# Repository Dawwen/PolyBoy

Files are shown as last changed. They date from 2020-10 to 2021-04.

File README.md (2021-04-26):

<p align="center">
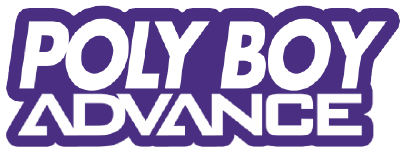
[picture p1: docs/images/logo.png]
PolyBoy Advance
  
</p>

# PolyBoy Advance

**Course :** Arduino

**Supervisors :** P. Masson, N. Abderrahmane

**Date :** December 2018 - March 2019

## Description

The goal of this project is to create a portable console based on Arduino Due. For this purpose, our portable console is equipped with a `TFT` screen, a `SD` card reader, a speaker, a gyroscope, a bluetooth module and other sensors and actuators. In the future, we think of developing an interface allowing to launch several games and applications.

## Authors

- [João Brilhante](https://github.com/JoaoBrlt)
- [Olivier Doussaud](https://github.com/Dawwen)

## License

This project is licensed under the GPLv3 License - see the [LICENSE](LICENSE) file for details.

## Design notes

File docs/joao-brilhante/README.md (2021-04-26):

<p align="center">
  Poly Boy Advance
</p>

## Une console portable basée sur Arduino Due
Notre projet est de créer une console portable basée sur Arduino Due. Elle sera notamment équipée d’un écran `LCD TFT`, d’un lecteur de carte micro `SD`, d’un haut-parleur, d’un gyroscope, d’un module bluetooth… De plus, elle devrait posséder une interface permettant de lancer plusieurs jeux et applications.

## Séance 1 : 14/12/18
Notre premier soucis a été de trouver un écran ayant une fréquence de rafraîchissement assez grande. En effet, dans le cadre des jeux vidéo, la fréquence de rafraîchissement est primordiale pour un affichage correct et des transitions fluides.

### Écran TFT à 8 bits en parallèle
<p align="center">
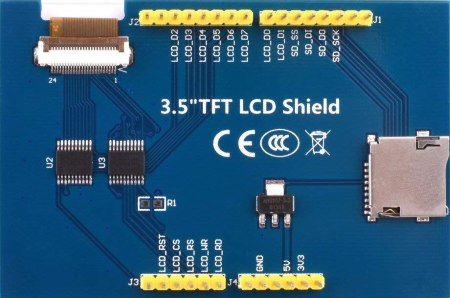
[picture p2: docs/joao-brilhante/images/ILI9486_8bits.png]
Écran TFT 8 bits de 3.5 pouces
  
</p>

Nous avons tout d’abord opté pour un écran `LCD TFT` (*Thin-Film Transistor*) ayant 5 pins de contrôle, 8 pins de communication et un contrôleur `ILI9486`.

En effet, nous pensions, à prime abord, que le nombre de pins de communication impacterait grandement la fréquence de rafraîchissement de l’écran.

Cependant, après quelques tests, nous avons constaté que l’écran pouvait prendre jusqu’à deux minutes pour rafraîchir individuellement chaque pixel avec une couleur aléatoire.

### Écran TFT à liaison SPI
<p align="center">
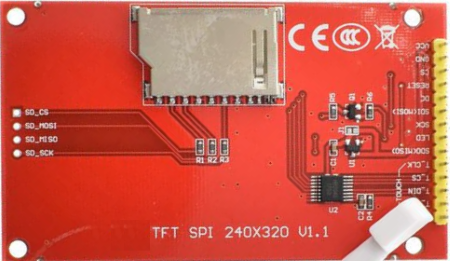
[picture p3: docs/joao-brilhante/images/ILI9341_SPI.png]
Écran TFT SPI de 3.2 pouces
  
</p>

Nous avons alors opté pour un écran `LCD TFT` à liaison `SPI` (*Serial Peripheral Interface*) qui n’utilise que 3 pins de contrôle, 4 pins de communication et un contrôleur `ILI9341`. L’avantage de la liaison `SPI` est son débit de données bien plus important notamment en mode `DMA` (*Direct Memory Access*).

De plus, après quelques recherches, nous avons trouvé une bibliothèque [ILI9341_due](https://github.com/marekburiak/ILI9341_due) très complète conçue pour notre contrôleur d'écran et pour Arduino Due. Cette bibliothèque correspond parfaitement à notre projet et implémente d'ores et déjà des fonctions d'affichage indispensables.

Après quelques tests, nous parvenons à afficher des textes, des formes et des images et à les animer. Cependant, nous avons toujours affaire à quelques artéfacts d'affichage qui sont dû à la fréquence de rafraîchissement de l’écran que nous devons prendre en compte.

## Séance 2 : 18/12/18
Nous nous répartissons les tâches et je décide d'attaquer la gestion de la mémoire. En effet, toujours dans le cadre des jeux vidéo, un de nos plus gros soucis sera le stockage et l'accès aux ressources telles que les images et les sons.

Nous décidons d'utiliser pour cela un module de carte micro `SD` à liaison `SPI`. En effet, la mémoire `SRAM` et `FLASH` offerte par l'Arduino Due n'est pas suffisante pour stocker toutes les ressources. De plus, cela nous permettra de stocker les ressources de tous les jeux sans avoir à reflasher l'Arduino Due.

### Module carte micro SD
<p align="center">
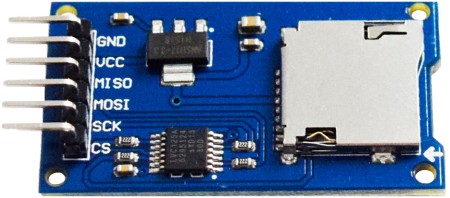
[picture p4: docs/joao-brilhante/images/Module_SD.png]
Module de carte SD
  
</p>

Après quelques recherches, je dois choisir entre deux bibliothèques de gestion de carte `SD` pour Arduino. La première bibliothèque [SD](https://www.arduino.cc/en/Reference/SD) est celle fournie par l'Arduino IDE. La deuxième bibliothèque [SdFat](https://github.com/greiman/SdFat) est celle que je choisis puisqu'il s'agit de la plus maintenue à jour par une communauté active. De plus, cette-denière permettrait un accès aux ressources bien plus rapide.

### Cartes micro SD
<p align="center">
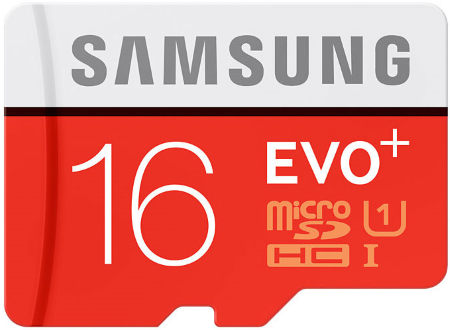
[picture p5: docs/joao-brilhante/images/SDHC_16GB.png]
Carte SDHC de 16 Go
  &nbsp;
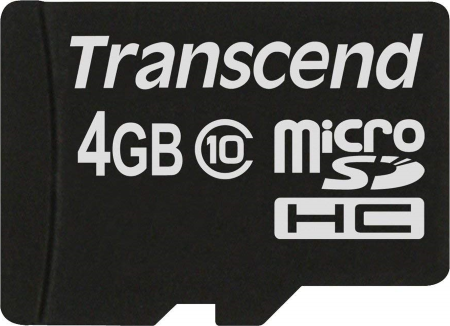
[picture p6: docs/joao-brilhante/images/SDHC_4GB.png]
Carte SDHC de 4 Go
  
</p>

Lors des premiers tests, il est nécessaire de trouver la plus grande fréquence de fonctionnement de notre carte micro `SD`. Dans un premier temps, j'essaie une carte micro `SDHC` de 16 Go et je constate que sa fréquence de fonctionnement est très basse. En effet, il semblerait que la fréquence de fonctionnement d'une carte `SD` soit d'autant plus grande que sa capacité est faible. Je décide alors d'utiliser une carte micro `SDHC` de 4 Go pour laquelle je trouve une fréquence de fonctionnement bien plus grande.

Il est ensuite très simple d'accéder à la mémoire et de manipuler les fichiers en lecture et en écriture. J'ajoute dès à présent une fonctionnalité permettant de désactiver la communication avec l'écran `TFT`, également en liaison `SPI`, lors de l'accès à la carte `SD` afin d'éviter les conflits.

## Séance 3 : 11/01/19
Dans l'optique d'un meilleur confort de jeu, nous décidons d'utiliser des boutons à membrane au lieu de boutons poussoirs. Je dois alors chercher les boutons, les membranes en caoutchouc et le circuit imprimé permettant leur fonctionnement. Malheureusement, les boutons à membrane sont souvent vendus sans le circuit imprimé, pour permettre la réparation de vieilles manettes.

### Manette de SNES
<p align="center">
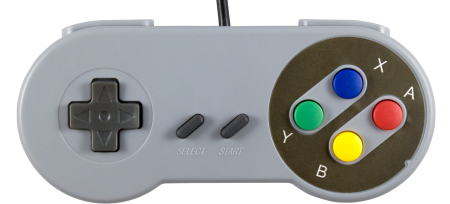
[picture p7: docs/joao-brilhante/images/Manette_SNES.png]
Manette de SNES
  
</p>

Je choisis une option assez simple qui consiste à réutiliser les composants d'une manette filaire de `SNES`.

### Composants de la manette
<p align="center">
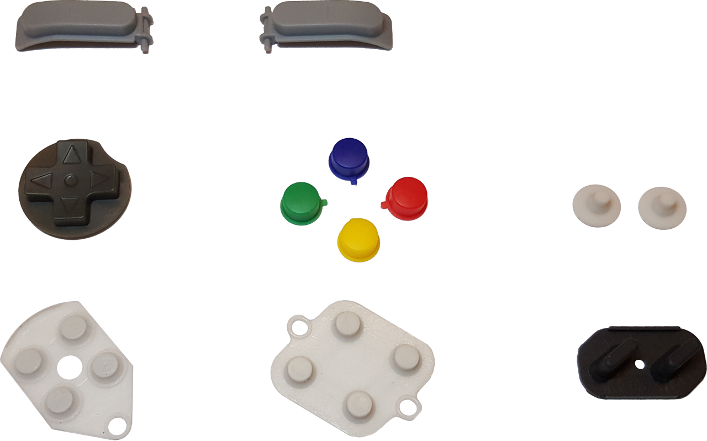
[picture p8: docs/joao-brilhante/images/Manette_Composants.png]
Composants de la manette
  
</p>

Il me suffit de démonter la manette puis de récupérer les boutons, les membranes et le circuit imprimé.

### Circuit imprimé de la manette
<p align="center">
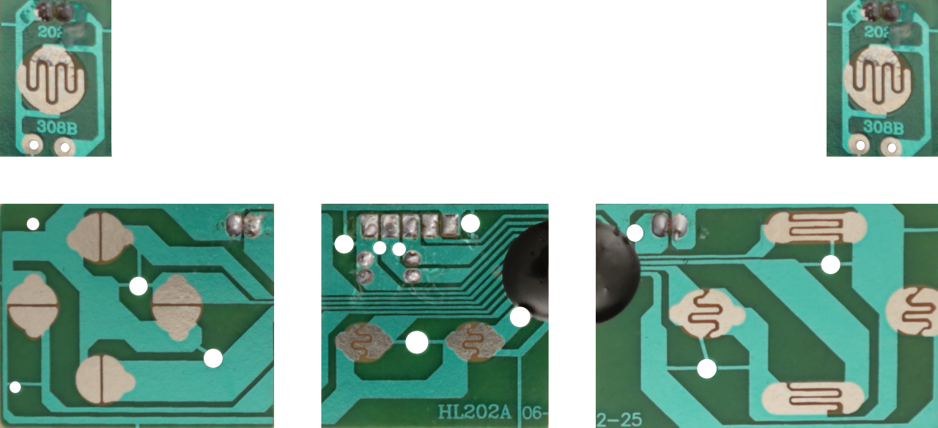
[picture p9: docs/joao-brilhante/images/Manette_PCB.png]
Circuit imprimé de la manette
  
</p>

Je découpe ensuite le circuit imprimé en cinq morceaux afin de pouvoir disposer les boutons plus aisément ultérieurement.
- Un morceau pour la croix directionnelle.
- Un morceau pour les boutons `Start` et `Select`.
- Un morceau pour les boutons `A`, `B`, `X` et `Y`.
- Deux morceaux pour les gachettes gauche et droite.

### Schéma du circuit imprimé
<p align="center">
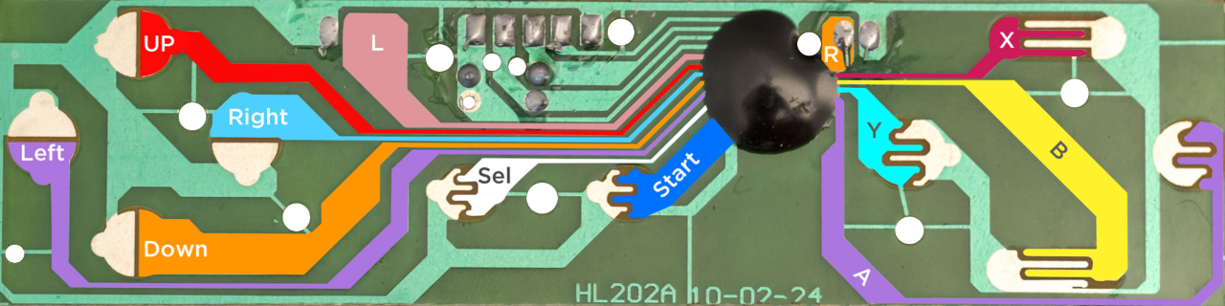
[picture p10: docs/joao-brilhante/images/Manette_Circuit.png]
Schéma du circuit imprimé
  
</p>

Enfin, je soude des fils sur les contacts des circuits imprimés afin de détecter la pression de chaque bouton. Pour l'instant, les fils sont suffisamment longs pour pouvoir disposer les boutons plus facilement lors du montage.

### Gestionnaire des boutons
Finalement, il ne me reste plus que le développement d'une bibliothèque permettant la gestion des boutons. Pour cela, je crée une structure de données pour pouvoir stocker toutes les informations des boutons telles que le nom, le pin, l'état, l'état précédent... etc.

Je développe ensuite une classe qui stocke tous les boutons et qui admet un certain nombre de fonctions. Ces fonctions permettent de récupérer facilement des informations utiles sur les boutons à partir de leur nom : le bouton est-il pressé ? le bouton a-t-il été relâché ? le bouton est-il pressé depuis un certain temps ? ... etc.

## Séance 4 : 18/01/19
Après ces quelques séances, nous avons déjà réussi à mettre en place la gestion de l'écran, des boutons et de la mémoire sur une carte micro `SD`. De ce fait, il nous semble important de réunir notre travail au plus vite pour valider ces fonctionnalités et aller plus loin dans le projet.

### Morpion
<p align="center">
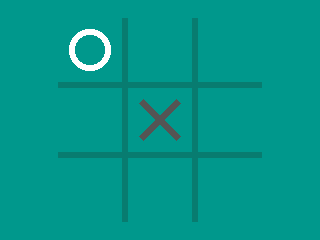
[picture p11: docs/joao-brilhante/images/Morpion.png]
Morpion
  
</p>

Je décide alors de coder le premier jeu simpliste de la console : un morpion ! Je commence par gérer l'affichage du jeu en utilisant les fonctions de la bibliothèque de l'écran. J'ajoute un sélecteur permettant de se déplacer et de valider son choix à l'aide des boutons à l'aide de la bibliothèque des boutons. J'implémente ensuite une vérification de victoire ou d'égalité des joueurs. Enfin, je crée un menu permettant au joueur de choisir son mode de jeu. En effet, le joueur peut choisir de jouer contre un autre joueur ou contre une intelligence artificielle simple.

### Modélisation 3D
<p align="center">
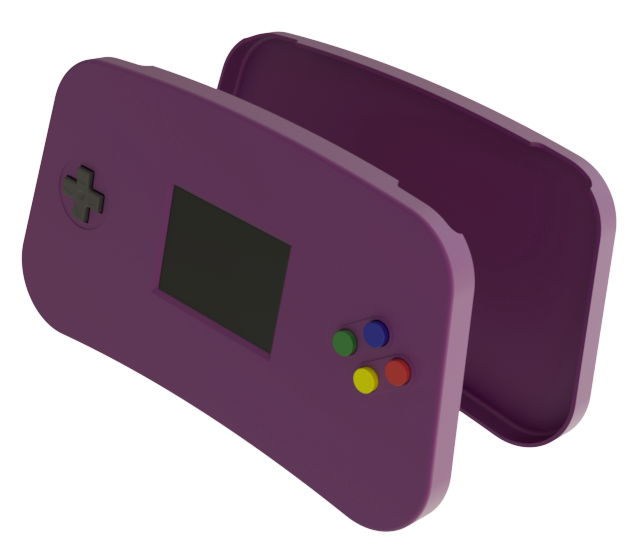
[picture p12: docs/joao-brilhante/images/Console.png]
Rendu 3D de la console
  
</p>

Afin d'obtenir le meilleur résultat possible, nous choisissons de faire imprimer en 3D le boitier de notre console. Pour cela, il est nécessaire de s'occuper d'ores et déjà de la modélisation 3D du boitier. J'utilise alors le logiciel <a href="https://www.autodesk.fr/products/inventor/overview">Inventor</a> pour modéliser l'intégralité des composants avec une grande précision pour un résultat au plus proche de la réalité. De plus, il est nécessaire de réfléchir à la meilleure disposition des composants pour la miniaturisation et l'ergonomie de la console.

### Quelques rendus
<p align="center">
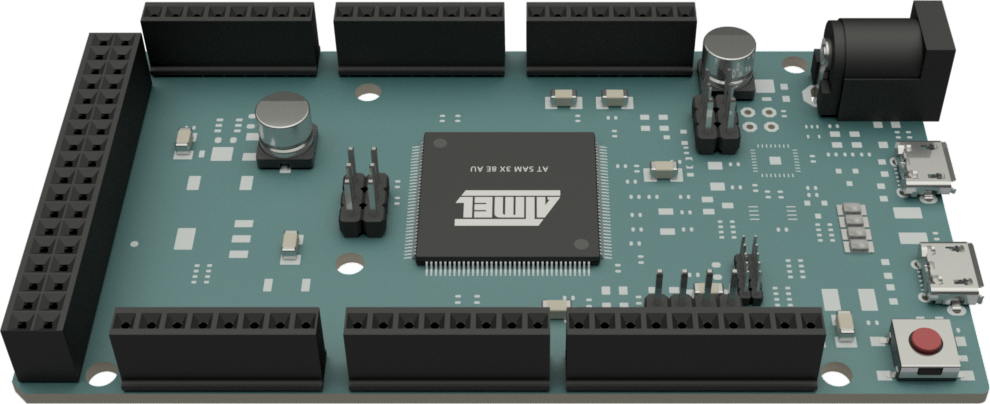
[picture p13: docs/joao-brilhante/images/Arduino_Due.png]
Arduino Due
  &nbsp;&nbsp;
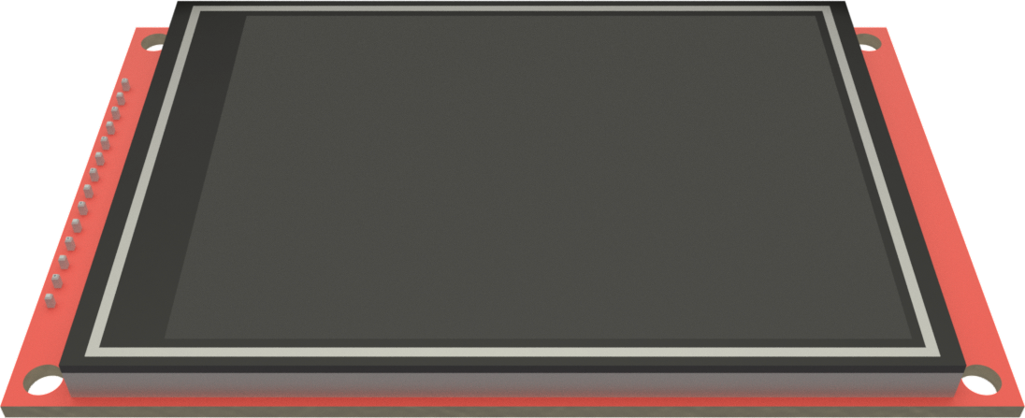
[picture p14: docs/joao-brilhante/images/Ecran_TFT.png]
Ecran TFT
  &nbsp;&nbsp;
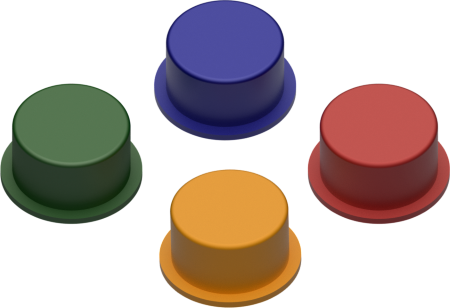
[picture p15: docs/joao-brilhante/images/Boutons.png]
Boutons ABXY
  &nbsp;&nbsp;
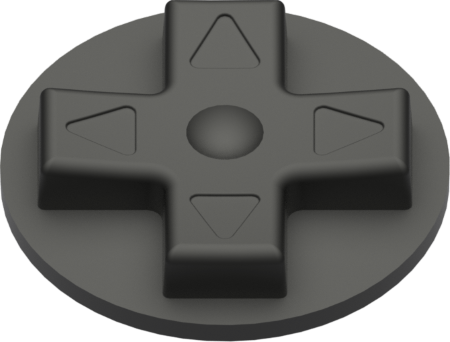
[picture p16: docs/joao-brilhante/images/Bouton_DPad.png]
Bouton des flèches directionnelles
  &nbsp;&nbsp;
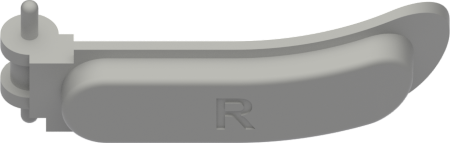
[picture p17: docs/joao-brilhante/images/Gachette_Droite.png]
Gachette droite
  &nbsp;&nbsp;
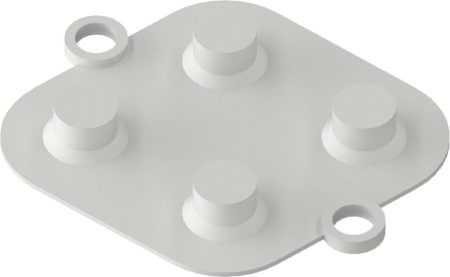
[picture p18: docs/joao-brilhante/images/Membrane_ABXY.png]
Membrane des boutons ABXY
  &nbsp;&nbsp;
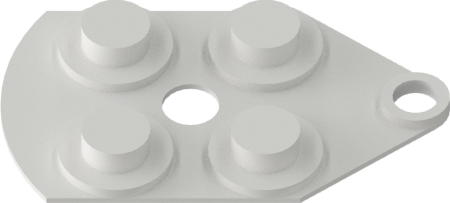
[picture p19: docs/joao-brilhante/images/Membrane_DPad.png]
Membrane du bouton des flèches directionnelles
  &nbsp;&nbsp;
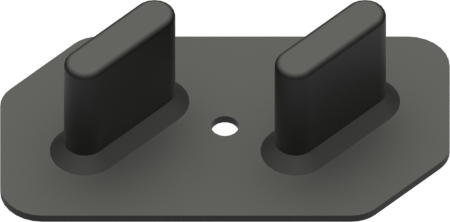
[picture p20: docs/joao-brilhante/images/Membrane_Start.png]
Membrane des boutons Start et Select
  
</p>

## Séance 5 : 05/02/19
Durant cette séance, je poursuis la modélisation 3D du boitier de la console. Le but est de penser au mieux la structure du boitier autant du point de vue extérieur, pour une bonne ergonomie et une certaine rigidité, que du point de vue intérieur, pour une bonne fixation des composants. De plus, je souhaite miniaturiser au maximum la console. L'enjeu est donc de taille puisque nous n'avons pas beaucoup d'espace pour les composants et plus beaucoup de temps pour réaliser des prototypes. Il s'agit alors de laisser une certaine marge à l'impression 3D pour mieux corriger et emboîter les deux parties du boitier a posteriori.

### Impression 3D
<p align="center">
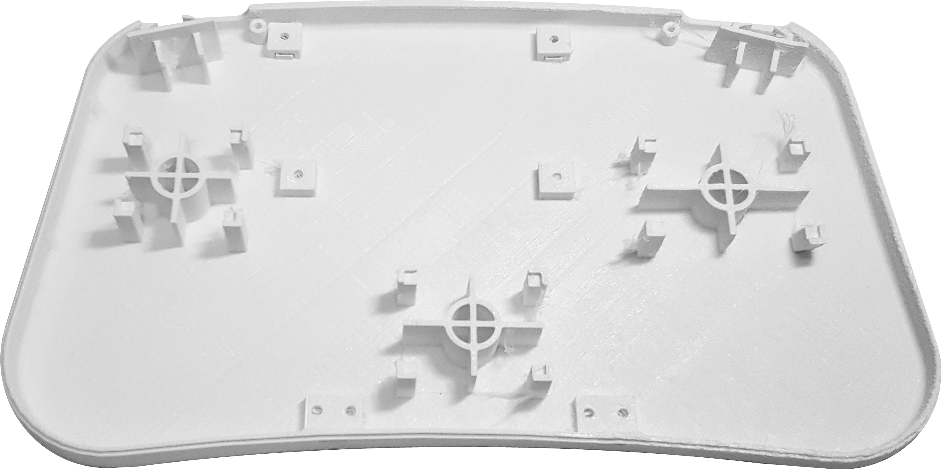
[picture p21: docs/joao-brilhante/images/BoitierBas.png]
Boitier bas
  
</p>

Une fois ce long processus terminé, je contacte le [SoFab](http://www.sofab.tv/), un atelier partagé de fabrication situé sur le campus Sophiatech, qui accepte notre projet d'impression 3D. Je parviens assez facilement à imprimer le bas du boitier. Cependant, pour l'impression 3D du haut du boitier, je suis confronté à un certain nombre de problèmes à cause de certaines extrusions. Après quelques aller-retour entre la modélisation et l'impression 3D, je parviens tout de même à imprimer le haut du boitier.

## Séance 6 : 13/02/19
L'impression 3D du boitier reste plutôt correcte cependant elle manque cruellement de précision.

### Corrections
<p align="center">
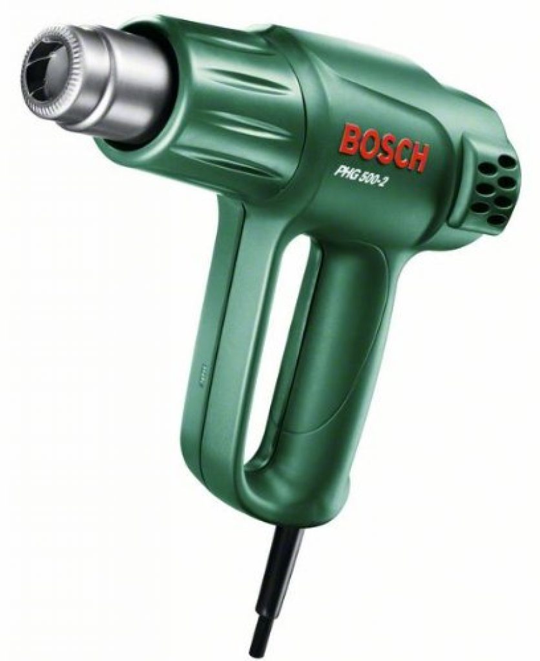
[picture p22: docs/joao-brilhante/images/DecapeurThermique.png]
Décapeur thermique
  &nbsp;&nbsp;
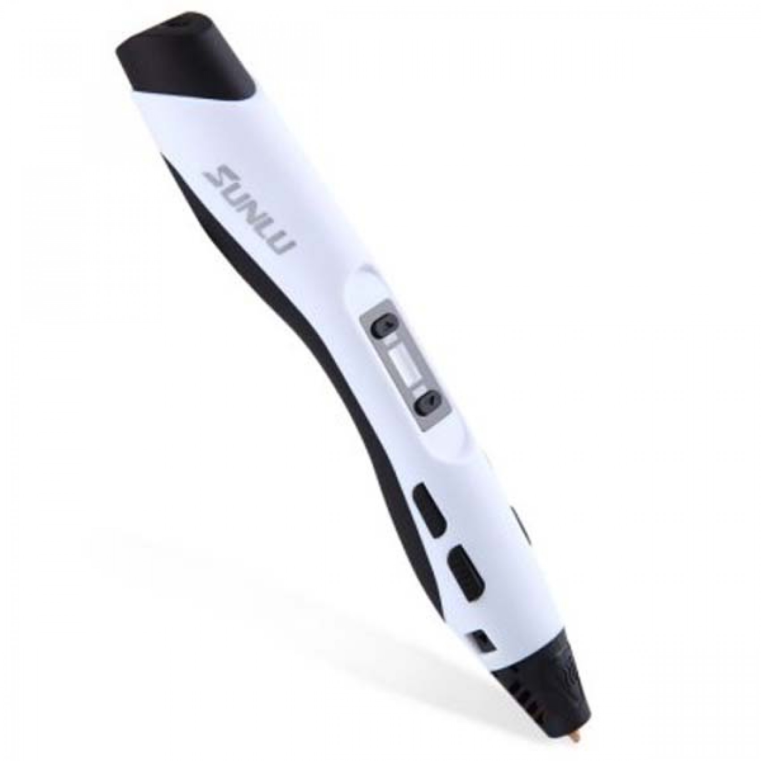
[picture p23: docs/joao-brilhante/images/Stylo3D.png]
Stylo 3D
  &nbsp;&nbsp;
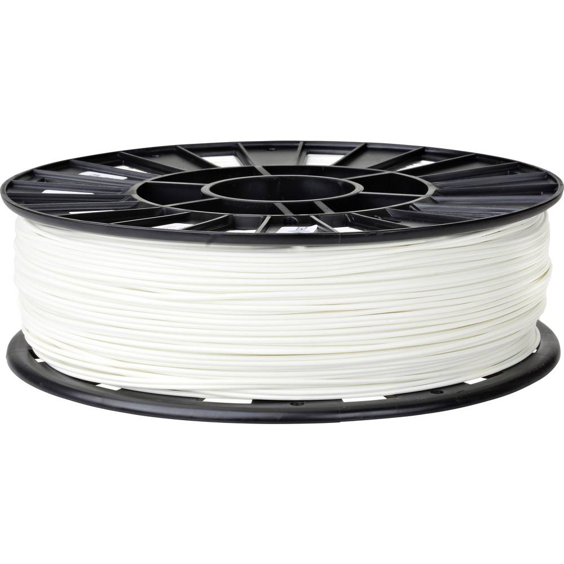
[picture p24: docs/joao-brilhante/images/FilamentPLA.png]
Filament PLA
  &nbsp;&nbsp;&nbsp;&nbsp;
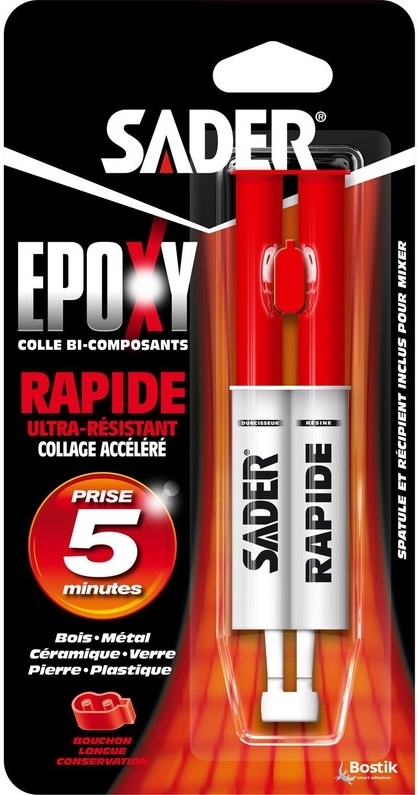
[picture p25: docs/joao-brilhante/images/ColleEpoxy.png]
Tubes de colle Epoxy
  
</p>

La prochaine étape est donc de corriger les erreurs d'impression en utilisant les mesures correctes du modèle 3D. Pour cela, j'utilise un décapeur thermique pour chauffer et redresser certaines parties du boitier. J'utile également un tube de colle Epoxy pour coller solidement certaines parties mal placées du boitier. J'utilise ensuite un stylo 3D accompagné d'un filament de PLA 1.75mm pour ajouter de la matière à certains endroits du boitier. Il ne me reste plus qu'à vérifier le bon emboitement et la fixation des composants à l'intérieur du boitier pour valider les corrections.

### Finitions
<p align="center">
  Mastic pour remplissage et finitions&nbsp;&nbsp;
  Peinture acrylique en spray&nbsp;&nbsp;
  Vernis mat en spray
</p>

Les deux parties du boitier s'emboitent désormais parfaitement. Je m'attaque donc au plus vite aux finitions. Pour cela, j'utilise un Mastic de remplissage et de finitions automobiles pour combler les creux des surfaces. Il me suffit d'appliquer la pâte sur les surfaces, d'attendre le séchage complet puis de poncer à l'aide de papiers abrasifs de différents grains et de manière progressive. J'applique ensuite trois couches de peinture violette acrylique en spray avant d'appliquer deux couches de vernis mat en spray.

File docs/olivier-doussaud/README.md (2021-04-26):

# PolyBoy Advance
## An Arduino Project
Notre projet est de créer une console portable basée sur Arduino Due. Elle sera notamment équipée d’un écran TFT, d’un lecteur de carte SD, d’un haut-parleur, d’un gyroscope, d’un module bluetooth… De plus, elle devrait posséder une interface permettant de lancer plusieurs jeux et applications.

### 14/12 : Séance 1
Après plusieurs recherches d'écrans :

1. **Un ili9486 3.5 inch** (8 pins de communications en parallèles)
2. **Un ili9341 3.2 inch** (16 pins de communications en parallèles)
3. **Un ili9341 3.2 inch** (communication en **SPI**)

On a décidé d'utiliser le **ili9341** en **SPI** qui était l'écran avec un rafraîchissement le plus rapide mais pas non plus suffisant. En cherchant plusieurs librairies qui n'accélérait pas le processus. On a trouve cette [librairie](https://github.com/marekburiak/ILI9341_due) avec une [video](https://www.youtube.com/watch?v=vnEwzN14BsU) montrant un mode du **SPI** plus rapide faite pour notre carte l'**Arduino Due**. Cette librairie accélère beaucoup le processus d'affichage et le met a un niveau suffisant pour faire des jeux. Cette librairie utilise le mode **DMA** ou Direct Memory Acess du **SPI** qui ne demande moins de ressource au micro-controller et permet l'exécution de code en parallele.

On arrive à afficher sur l'écran des formes géometriques et des images de toutes tailles. Le problème est d'afficher une image sur un **background**. On a reussi à afficher au maximum un **background** et un **sprite** dessus ([link](https://www.youtube.com/watch?v=tJE1cOGFOp4&feature=youtu.be)).
On a quand même un problème d'affichage liée au rafraichîssement de l'écran qui a pu être en partie reparé avec l'ajout d'un cap au **framerate** (nombre de fois que l'on finis un nouvelle frame en 1 seconde). On a donc bloqué le **framerate** à 60 **frame** par seconde. Le but maintenant est de faire que l'on ne rafraîchisse que la partie nécessaire de l'écran pour encore augmenter la vitesse et encore réduire les problèmes d'affichages.

### 18/12 : Séance 2

On a ajouté un **script** python pour convertir les images **bmp** en un **tableau** lisible par l'arduino. Ce **tableau** est à 1 dimension et contient les couleurs en valeur numérique codées en **RGB 565** (5 bits pour le rouge, 6 bits pour le vert et 5 bits pour le rouge). Cela nous permettra de facilement copier des images sur l'arduino et de les afficher. On a aussi travaillé sur la **gestion de l'affichage** de l'écran. Avant on redessiner complètement le **background** pour chaque nouvelle **frame** puis les **sprites** qui étaient au 1er plan. Cette méthode n'étant pas des plus rapide et ajoutant au problèmes que l'on puisse dessiner pendant que l'écran se rafraîchisse.  On a créé une **classe** sprite qui redessinera que les zones modifiées de l'écran, diminuant les données à envoyer entre l' **écran** et l'**arduino due**. On a cependant eu un problème avec notre **librairie**, la modification du bas de l'ecran, ne redessinait pas la bonne partie du **background** (elle dessinait le partie haute du background avec un decalage).  Le problème venant que la librairie codait l'**offset** sur **16bits** au lieu de **32bits** ce qui faisait que l'offset ne pouvait  pas atteindre les dernieres valeurs du background. On a ajouter des méthodes a la **librairie** pour résoudre ce problème en codant l'**offset** sur **32bits**.

Les problèmes persistant sont :

1. Le fait que l'on puisse dessiner pendant que l'écran se rafraîchisse (fait que le sprite se mélange au background)
2. On ne dispose pas de transparence sur l'ecran pour le moment

### 11/01 : Séance 3

Je me suis occupé du problème de transparence que l'on avait. Pour gerer la transparence je dois choisir une couleur qui sera consideré comme transparent la couleur utilisé communement est le **magenta** . Pour résoudre ce problème j'ai modifié notre **script** qui transfornait les images **bmp** en fichier pour l'arduino.A la place de copier tout l'image je regarde le contour du contenu de l'image et je prend que ce qu'il y a à l'interieur. Ce qui fait que les sprites n'auront pas forcément de forme carré. Cela ne gére que une partie de la transparence, cela permet d'enlever les fond noir de l'image mais laisse les pixel magenta à l'interieur du contour visible.

<p align="center">
  1ere essai de transparence
</p>

Pour résoudre ce problème on doit s'occuper du coté de l'arduino et plus spécifiquement du coté de la librairie. J'ai modifié la librairie en faisant que quand il affiche un **sprite** si la couleur est **magenta** il n'affiche pas **magenta** mais la couleur du **background** ce qui corrige le problème restant.

<p align="center">
  1ere essai de transparence
</p>

J'ai aussi commencé à travailler sur la partie wifi de notre projet j'ai réussi a envoyer un msg de l'**esp8266** à l'ordinateur sans plus.

### 11/01 : Séance 4

Je me suis occupé de la partie **serveur web** (Un serveur qui contiendra tout les meilleurs scores). On aura donc un autre ordinateur (possiblement un raspberry Pi) qui stockera toutes ces données et les modifira en fonction de ce que fera notre console.Notre console pourra donc pour chaque jeux recupérer les **High-scores** et aussi envoyer son score pour le rajouter au **High-Scores**. Le serveur que j'ai commencé a faire en python permet que d'envoyer le contenu de fichier a des client et a rajouter du contenu dans un fichier et vérifier si la communication a fonctionné.
Exemple de requetes :

**READ sokoban 1 10 23** : Demande le High-score des 10 premiers joueurs a sokoban(READ: type de requete, sokoban: le jeu en question, 1:debut du tableau, 10: fin du tableau, 23: nombre permettant de vérifier si la commu a réussi)

**WRITE sokoban Olivier 200 48** : Demande de rajouter au scores du jeu sokoban le joueurs Olivier avec un score de 200

Ce type de requete fonctionne pour le moment mais je compte les rendres plus précise (High-score par niveau la c'est défini par jeu).

### 06/02 : Séance 5

J'ai continué à travailler sur la partie serveur pour gérer la partie score des jeux. J'ai séparé la partie du code qui envoyait et modifiait les scores.J'en ai aussi profité pour le passer sous forme d'objet qui sera plus simple a modifer/gérer.Le code peut maintenant être executé sur un **thread**(indépendant du reste tourne en parallèle).J'ai aussi travaillé sur du code pour pouvoir modifier le serveur avec des commandes (Comme sur un terminal).

On a aussi dans l'idée de faire que la console(arduino) puisse jouer en **multijoueur** avec une autre console mais aussi pouvoir mettre ses scores sur le serveurs. J'ai donc aussi installé et commencé a utiliser **[VitaSDK](https://vitasdk.org/)** qui permet de développer sur Psvita. Cette console ayant tout se qui nous sera nécessaire.

1. Une connexion **Wifi** qui sera utilisé pour le multijoueur
2. Un portage d'une librairie **graphique** assez utilisé sur ordinateur(facilise les recherches et le portage vers Pc si nécessaire)

Pour l'instant sur la Psvita on peut afficher du text et des formes géometriques. On peut acceder au bouton de la console et la partie sans-fil. Notre code sur la console peut pour le moment afficher du text, envoyer une requete au serveur et afficher le contenu reçu.

### 13/02 : Séance 6

J'ai fait un schéma des différentes parties du la partie web de notre projet:
<p align="center">
  Architecture du serveur
</p>

Les différentes parties sont :
1. **Score Server**: La partie qui recoit des requètes de modification ou de lecture de high-score
2. **Main Thread**: Permet de gerer les différentes partie du serveur (ex: les allumé ou non)
3. **Game Core**: La partie ou est calculé la physique du jeu
4. **Game Server**: La partie qui envoie le status du jeu et recoit les informations des consoles

Les parties **Score Server** et **Main Thread** sont terminé. J'ai aussi commencé a faire le traitement de la reception des requètes par l'**esp8266**.

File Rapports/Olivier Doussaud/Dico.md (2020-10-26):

**Programation Objet** :
	C'est une maniere de programmer où on créer des classes qui sont comme des moules pour ensuite créer des objet basée sur ces moules. Les objets ont alors des variable propre appelé attribut et des fonctions propre appelé méthode.

**SPI** :
	C'est un système de communication série sychrone.

**background** : C'est l'image en fond (en dernier plan)

**sprite** : Image en premier plan (souvent les personnage objet)

**frame** : C'est l' image afficher par l'écran

**framerate** : C'est le nombre de frame affiché par seconde

**script** : C'est un programme

**bmp** : c'est un format d'image

**RGB** : Rouge Vert Bleu ce sont les couleurs qui constituent 1 pixel

**librairie** : Ensemble de fonctions et de variable.

**offset** : valeur donnant la 1ere valeur d'un index

**High-score** : Les noms et scores des meilleurs joueurs

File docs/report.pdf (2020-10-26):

La Poly Boy Une console portable basée sur Arduino Due.


## Rapport de Projet Arduino

Étudiants :
Joao BRILHANTE
Olivier DOUSSAUD

Enseignants :
Pascal MASSON
Nassim ABDERRAHMANE

Mars 2019

## Remerciements

Nous tenons à remercier tout particulièrement Monsieur Marek Buriak, l’auteur de la bibliothèque d’affichage ILI9341_due, sans quoi le projet n’aurait pu avancer aussi vite. De plus, un grand merci à toute l’équipe de VitaSDK, un kit de développement pour la PS Vita, une console portable de Sony. Enfin, nous souhaitons remercier Messieurs Pascal Masson et Nassim Abderrahmane pour ce cours d’électronique sur Arduino qui nous a permis de mettre en pratique nos connaissances.

## Sommaire

1 Introduction | 4
2 Matériel utilisé | 5
3 Fonctionnement et schémas | 10
4 Difficultés | 16
5 Conclusion | 17

## 1 Introduction

### 1.1 Présentation

Ce projet intitulé Poly Boy, en référence à la célèbre console portable de Nintendo, est une console portable basée sur Arduino Due. En effet, tous deux passionnés de jeux vidéo et de développement, nous avons décidé d’offrir la meilleure expérience de jeu possible sur ce support. La console est notamment équipée d’un lecteur de carte micro SD permettant au joueur de télécharger tous les jeux développés pour cet environnement. Ainsi, le joueur a la possibilité de redécouvrir ses jeux préférés sur une console portable ergonomique et économique. Enfin, une communication réseau permet à ce dernier de profiter d’une aventure en multi-joueurs quelle que soit la distance.

### 1.2 Objectifs

Nous tenions à offrir la meilleure expérience de jeu possible et à nous démarquer de nos prédécesseurs. Pour cela, nous avons dressé une liste des objectifs primordiaux à atteindre :
- Une console portable basée sur Arduino Due.
- Un affichage rapide et fluide pour une bonne immersion.
- Une communication Wi-Fi pour accéder aux meilleurs scores et au multi-joueurs.
- Des boutons à membrane plus confortables et réactifs que des boutons poussoirs.
- Un boitier solide et élégant permettant une bonne prise en main de la console.
- Un lecteur de carte SD pour le stockage des jeux et des ressources nécessaires.
- Un port micro USB permettant la programmation de la console à tout instant.
- Un gyroscope pour les jeux nécessitant une capture des rotations et du mouvement.
- Un son mono pour accentuer l’immersion et la nostalgie.
- Une interface de lancement des jeux et applications depuis la carte SD.

## 2 Matériel utilisé

### 2.1 Écran TFT

Notre première priorité a été de trouver un écran ayant une fréquence de rafraîchissement assez grande. En effet, dans le cadre des jeux vidéo, la fréquence de rafraîchissement est primordiale pour un affichage correct et des transitions fluides.


Figure 1: Ecran TFT à 8 bits en parallèle

Nous avons tout d’abord opté pour un écran TFT (Thin-Film Transistor) ayant 5 pins de contrôle, 8 pins de communication et un contrôleur ILI9486. En effet, nous pensions, à prime abord, que le nombre de pins de communication impacterait grandement la fréquence de rafraîchissement de l’écran. Cependant, après quelques tests, nous avons constaté que l’écran pouvait prendre jusqu’à deux minutes pour rafraîchir individuellement chaque pixel avec une couleur aléatoire.


Figure 2: Ecran TFT à liaison SPI

Nous avons finalement opté pour un écran TFT à liaison SPI (Serial Peripheral Interface) qui n’utilise que 3 pins de contrôle, 3 pins de communication et un contrôleur ILI9341. L’avantage de la liaison SPI est son débit de données bien plus important notamment en mode DMA (Direct Memory Access).

### 2.2 Carte SD

Une de nos priorités a également été de trouver une solution au stockage des ressources des différents jeux et applications de la console. En effet, les données de jeux peuvent être assez gourmandes en mémoire.


Nous décidons d'utiliser pour cela un module de carte micro SD à liaison SPI. En effet, les mémoires SRAM et FLASH offertes par l'Arduino Due ne sont pas suffisantes pour stocker toutes les ressources. De plus, cela nous permettra de stocker les ressources de tous les jeux sans avoir à reflasher l'Arduino Due.

Dans un premier temps, nous essayons une carte micro SDHC de 16 Go et nous constatons que sa fréquence de fonctionnement est très basse. En effet, il semblerait que la fréquence de fonctionnement d'une carte micro SD soit d'autant plus grande que sa capacité est faible. Nous décidons alors d'utiliser une carte micro SDHC de 4 Go et de classe 10 pour laquelle nous trouvons une fréquence de fonctionnement plus raisonnable.

Figure 3: Module de carte micro SD

Figure 4: Carte micro SDHC de 16 Go | Figure 5: Carte micro SDHC de 4 Go

### 2.3 Boutons

Dans l'optique d'un meilleur confort de jeu, nous avons décidé d'utiliser des boutons à membrane au lieu de boutons poussoirs. Nous devons alors chercher les boutons, les membranes en caoutchouc et le circuit imprimé permettant leur fonctionnement. Malheureusement, les boutons à membrane sont souvent vendus sans le circuit imprimé, pour permettre la réparation de vieilles manettes.


Nous choisissons alors une option plus simple qui consiste à réutiliser les composants d'une manette filaire de SNES. Nous démontons la manette et récupérons les boutons, les membranes et le circuit imprimé.


Nous découpons ensuite le circuit imprimé en cinq morceaux :
- Un morceau pour la croix directionnelle.
- Un morceau pour les boutons Start et Select.
- Un morceau pour les boutons A, B, X et Y.
- Deux morceaux pour les gâchettes gauche et droite.

En effet, cela permettra de disposer les boutons plus aisément ultérieurement. Enfin, nous soudons fils sur les contacts des circuits imprimés afin de détecter la pression de chaque bouton à l’aide d’une résistance de tirage interne à l’Arduino Due.

Figure 6: Manette de SNES | Figure 7: Composants de la manette

Figure 8: Circuit imprimé de la manette

### 2.4 ESP8266

L’ESP8266 est un microcontrôleur développé par le fabricant chinois Espressif. Cette puce possède en outre l’avantage d’avoir un prix plus abordable que son équivalent Arduino (moins de 2 euros) et permet de communiquer en Wi-Fi. Cette-dernière ne s’est démocratisée que récemment après de la traduction de la documentation du chinois à l’anglais.


Notons que le même fabricant a également développé de nouvelle puces, telles que l’ESP32, qui en plus de la communication Wi-Fi permettent une communication Bluetooth. Pour notre projet, nous choisissons l’ESP8266 puisque nous n’aurons besoin que de la communication Wi-Fi.

Figure 9: ESP8266 MiniDK avec écran OLED

### 2.5 Boitier

Nous choisissons de faire imprimer en 3D le boitier de notre console. Pour cela, nous devions nous occuper au plus tôt de la modélisation 3D du boitier. Nous utilisons alors le logiciel SolidWorks pour modéliser l'intégralité des composants avec une grande précision pour un résultat au plus proche de la réalité.


De plus, il est nécessaire de réfléchir à la meilleure disposition des composants pour la miniaturisation et l'ergonomie de la console. Nous n'avons pas beaucoup de temps pour réaliser des prototypes et d'espace pour les composants. Il s'agit alors de laisser une certaine marge à l'impression 3D pour mieux corriger et emboîter les deux parties du boitier a posteriori.


Une fois ce long processus terminé, nous contactons le SoFab, un atelier partagé de fabrication situé sur le campus SophiaTech, qui accepte notre projet d'impression 3D. L'impression 3D reste plutôt correcte cependant elle manque cruellement de précision. Nous nous occupons alors des finitions du boitier.

Figure 10: Modélisation 3D du boitier | Figure 11: Modélisation 3D de l’Arduino Due

Figure 12: Boitier de la console

## 3 Fonctionnement et schémas

### 3.1 Affichage

Après quelques recherches, nous trouvons une bibliothèque ILI9341_due très complète conçue pour notre contrôleur d'écran et pour Arduino Due. Cette bibliothèque correspond parfaitement à notre projet et implémente d'ores et déjà des fonctions de communication SPI et d’affichage indispensables.


Nous parvenons très rapidement à afficher des textes, des formes et des images et à les animer. Cependant, nous avons toujours affaire à quelques artéfacts d'affichage qui sont dus à la fréquence de rafraîchissement de l’écran que nous devons prendre en compte.


Nous imaginons ensuite une bibliothèque permettant l’implémentation d’autres fonctions utiles et une initialisation plus simple de l’écran. En effet, lors du développement des jeux, nous aurons besoin de pouvoir afficher des images avec ou sans transparence. De plus, nous ajoutons la gestion de feuille de sprites, des tableaux de toutes les images nécessaires à l’affichage d’un objet ou personnage.

Figure 14: Une feuille de sprites | Figure 15: Une image de fond

Figure 13: Schéma d’une liaison SPI

### 3.2 Fichiers

Afin gérer l’accès à la mémoire de la carte SD, nous devions choisir entre deux bibliothèques. La première bibliothèque SD est celle fournie par l'Arduino IDE. La deuxième bibliothèque SdFat est celle que nous choisissons puisqu'il s'agit de la plus maintenue à jour par une communauté active. De plus, cette-dernière permettrait un accès aux ressources bien plus rapide.


Il est ensuite très simple d'accéder à la mémoire et de manipuler les fichiers en lecture et en écriture. Nous imaginons encore une fois une bibliothèque permettant une initialisation plus simple de la carte SD et de désactiver la communication avec l'écran TFT, également en liaison SPI, lors de l'accès à la mémoire afin d'éviter les conflits.

Figure 16: Schéma d’une liaison SPI à plusieurs esclaves

### 3.3 Boutons

Une fois les circuits des boutons soudés et testés, il est nécessaire d’accéder facilement à l’état de pression des boutons. Pour cela, nous imaginons une bibliothèque permettant un accès simple et explicite à l’état et aux évènements des boutons.


Il est ainsi possible de savoir si un bouton est pressé, s’il est pressé depuis une certaine durée ou bien s’il vient d’être pressé ou relâché. Cette bibliothèque représente donc un pilier du développement des jeux pour la console.

Figure 17: Fonctions disponibles. | Figure 18: Exemple d’utilisation.

### 3.4 Réseau

Pour notre projet, nous utilisons un Arduino Due et un ESP8266. L’Arduino s’occupe ainsi de la gestion du jeu et l’ESP8266 gère la communication Wi-Fi. Nous avons également développé deux serveurs pour la communication avec l’ESP. Nous utilisons l’ESP uniquement pour transférer les requêtes au serveur et les réponses à l’Arduino par la communication série.


Figure 19: Schéma de fonctionnement de la communication réseau.

### 3.5 Serveur

Pour la partie connectée de notre console, nous avons développé plusieurs serveurs de communication afin de rajouter des fonctionnalités.
- Un serveur contenant pour chaque jeu, les scores et les noms des joueur pour sauvegarder un tableau des meilleurs joueurs. L’intérêt de le mettre sur un serveur est que les données ne sont pas sauvegardées sur la console. De plus, nous pourrions ajouter un site web qui afficherais le tableau de score de chaque jeu.
- Un serveur pour faire tourner des jeux en multi-joueurs. Ce serveur est lié à un « Game Core », un objet qui contient la logique de jeu et l’état du jeu. Ce serveur vérifie que les personnes qui communiquent avec lui sont bien des joueurs de la partie en cours et répond aux requêtés envoyées par la console (voir l’état du jeu, déplacement à tel position, etc…).
Pour gérer ces serveurs nous avons créé un programme sur lequel on rentre des commandes pour démarrer/éteindre le serveur, voir quel serveur est allumé et afficher ou non ce que font les serveurs. Il s’agit de la partie « Manager ».


Figure 20: Schéma de fonctionnement des serveurs.


### 3.6 Circuit

Figure 21: Circuit de la console.

## 1 Difficultés

### 3.1 Son

Notre première difficulté a été la gestion du son. En effet, nous n’avions pas beaucoup de temps et de connaissances sur le sujet. Nous avons notamment cassé le DAC (Digital to Analog Converter) de notre premier Arduino Due à cause d’une résistance manquante sur l’amplificateur audio.


### 3.2 Mouvement

Enfin, notre deuxième difficulté a été la mise en place du gyroscope. En effet, nous avons eut un problème d’espace dans le boitier. De plus, les valeurs reçues du gyroscope étaient erronées. Cela était sans doute dû à un défaut de fabrication de notre gyroscope. Cependant, encore une fois nous n’avions plus le temps d’effectuer les vérifications nécessaires.

Figure 22: Circuit pour le son.


Figure 23: Circuit pour le gyroscope.

## 2 Conclusion

### 3.1 Planning


### 3.2 Perspectives

Notre projet est terminé cependant si nous avions eu plus de séances, nous aurions beaucoup d’idées pour l’améliorer. Avec l’état actuel de nos connaissances, nous avons dressé une liste des éléments qui amélioreraient grandement l’expérience de jeu :
- Ajouter une batterie pour pouvoir jouer sans chargeur.
- Ajouter un capteur de luminosité pour régler la luminosité de l’écran.
- Ajouter un gyroscope pour capturer les rotations et les mouvements.
- Implémenter le son pour accentuer l’immersion.
- Développer un lanceur de jeux et d’applications.
- Développer différents jeux et applications.

Figure 24: Planning et suivi de progression.

## Références

[1] Marek Buriak, ILI9341_due, (http://marekburiak.github.io/ILI9341_due/) Bibliothèque d’affichage.
[2] Ilitek, ILI9341, (https://cdn-shop.adafruit.com/datasheets/ILI9341.pdf) Documentation du contrôleur ILI9341.
[3] Electronics Hub, Basics of Serial Peripheral Interface, (https://www.electronicshub.org/basics-serial-peripheral-interface-spi/) Introduction à la liaison SPI.
[4] Bill Greiman, SdFat, (https://github.com/greiman/SdFat/tree/master/extras/html) Bibliothèque de gestion de la carte SD.
[5] Rinnegatamante, TheOfficialFloW et devnoname120, VitaSDK, (https://wiki.henkaku.xyz/vita/Main_Page) Bibliothèque de développement pour la PS Vita.
[6] Communauté Arduino, ESP8266Wifi, (https://arduino-esp8266.readthedocs.io/en/latest/esp8266wifi/readme.html) Bibliothèque de communication Wi-Fi de l’ESP8266.
[7] Communauté Arduino, ESP8266, (https://media.readthedocs.org/pdf/arduino-esp8266/docs_to_readthedocs/arduino-esp8266.pdf) Documentation de l’ESP8266.
[8] Communauté Arduino, Arduino Due, (https://www.arduino.cc/en/Guide/ArduinoDue) Documentation de l’Arduino Due.
[9] Adafruit, Preparing the Buttons, PiGRRL, (https://learn.adafruit.com/pigrrl-raspberry-pi-gameboy/buttons) Tutoriel pour préparer le circuit des boutons.

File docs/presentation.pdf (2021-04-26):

Joao Brilhante
Olivier Doussaud


Sommaire

I. Introduction
a. Motivations
b. Objectifs
c. Problématique

III. Matériel
a. Ecran TFT
b. Lecteur Carte SD
c. ESP8266
d. Manette SNES

IV. Conclusion
a. Planning
b. Problèmes
c. Perspectives

II. Fonctions
a. Affichage
b. Mémoire
c. Wi-Fi
d. Boutons

# Sommaire

# MOTIVATIONS


- Une console portable basée sur Arduino Due.
- Une console connectée.
- Un boitier ergonomique et élégant.
- Un affichage propre et efficace.
- Des boutons confortables.
- Un son clair en mono.
- Un port USB pour reprogrammer.

# OBJECTIFS

## Comment réaliser une console portable connectée sur Arduino ?

# PROBLEMATIQUE



Ecran TFT de 3.2 Pouces en SPI


Ecran TFT de 3.2 pouces en 8 bits

# ECRAN TFT

Une liaison SPI (pour Serial Peripheral Interface) est un bus de données série synchrone. Les circuits communiquent selon un schéma maître-esclaves, où le maître contrôle la communication.

# ECRAN TFT



Par Marek Buriak

# Affichage

# Lecteur de carte SD


Lecteur de carte SD


Carte microSD


Carte microSD

# Memoire


## Spritesheet

## Fond

# ESP8266


## ESP8266


## Schéma des entrées/sorties

WI

-Fi | Wi


-Fi

# Manette SNES


Tache : Refonte de la partie graphique pour utiliser la carte SD. Date prévue : 11/01/2019
Date rendu : 26/02/2019
Raison: Création du boitier de la console gestion des boutons.

Tache : Finition de la partie serveur de scores.
Date prévue : 11/01/2019
Date rendu : 06/02/2019
Raison: Quelques erreurs à corriger.

Tache: Finition de la partie gestionnaire de serveur et serveur de jeu. Date prévue : 06/02/2019
Date rendu : 13/02/2019
Raison: Correctif après l'implémentation du jeu sur console.

Tache : Finition du boitier.
Date prévue : 06/02/2019
Date rendu : 13/02/2019
Raison : Manque de précision de l' impression 3D et donc du travail supplémentaire.

# Planning

# Problèmes résolus :

- Trouver un écran assez rapide.
- Gérer de la transparence.
- Imprimer le boitier de la console.
- Gérer de la Wi-Fi et des interférences.

# Problèmes non résolus :

- Gérer du son.
- Ajouter les gâchettes.

# Problemes

- Gérer le son à l’aide du DAC de l’Arduino Due.
- Ajouter les gâchettes.
- Ajouter une batterie.
- Ajouter un gyroscope.
- Développer un lanceur de jeux.
- Développer différents jeux.

# PerspectiveS

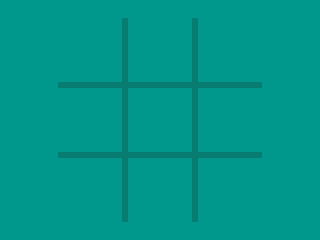
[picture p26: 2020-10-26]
docs/joao-brilhante/images/Morpion2.png

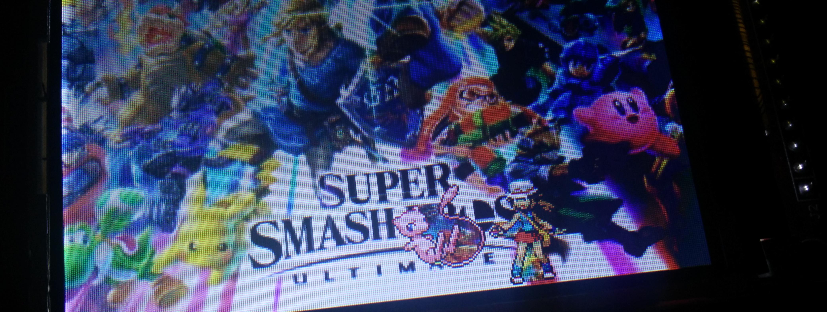
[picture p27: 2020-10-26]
docs/olivier-doussaud/images/tranparence_2.jpg

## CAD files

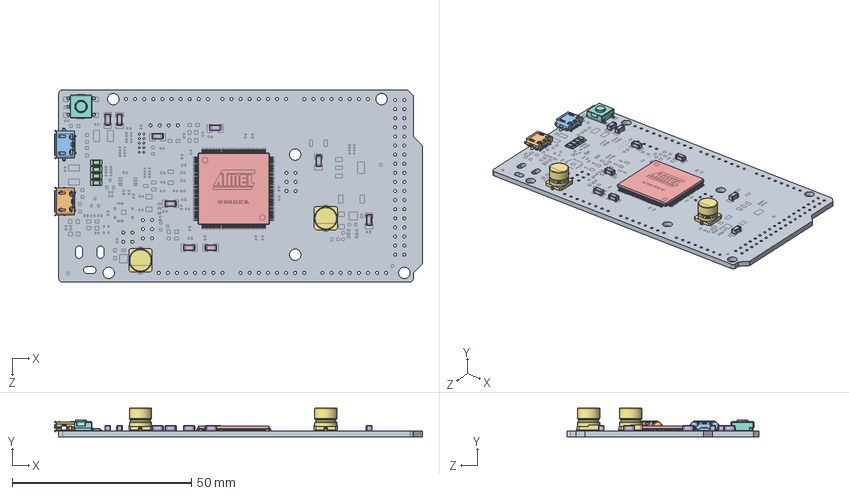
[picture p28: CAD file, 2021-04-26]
models/ArduinoDue.SLDASM
102.8 x 8.08 x 53.6 mm
PCB - Arduino
MicroUSB B - Hirose - ZX62D-B-5P8
MicroUSB AB - Hirose - ZX62D-AB-5P8
LED - Kingbright - KPT-3216EC x 4
Microchip - Atmel - SAM3X8EAU
Capacitor x 9
Capacitor - Nichicon - UUR1C101MCL1GS x 2
Switch - ESwitch - TLE3303

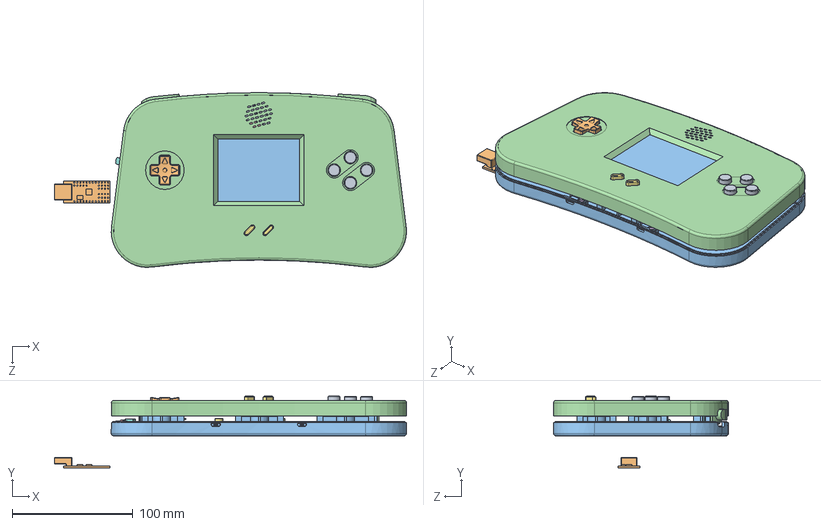
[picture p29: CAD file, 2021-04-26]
models/Console.SLDASM
292.0 x 59.3 x 145.0 mm
PCB - Arduino
MicroUSB B - Hirose - ZX62D-B-5P8
MicroUSB AB - Hirose - ZX62D-AB-5P8
LED - Kingbright - KPT-3216EC x 4
Microchip - Atmel - SAM3X8EAU
Capacitor x 9
Capacitor - Nichicon - UUR1C101MCL1GS x 2
Switch - ESwitch - TLE3303
Bouton x 4
DPad
Ecran
Gachette x 2
MembraneABXY
MembraneDPad
MembraneStart
Interrupteur
USBBreakout x 2
MembraneGachette x 2
PlaqueABXY
PlaqueDPad
PlaqueGachette1
PlaqueGachette2
PlaqueStart
BoitierBas
BoitierHaut
Boulon x 14
Vis8mm x 12
Vis4mm x 2

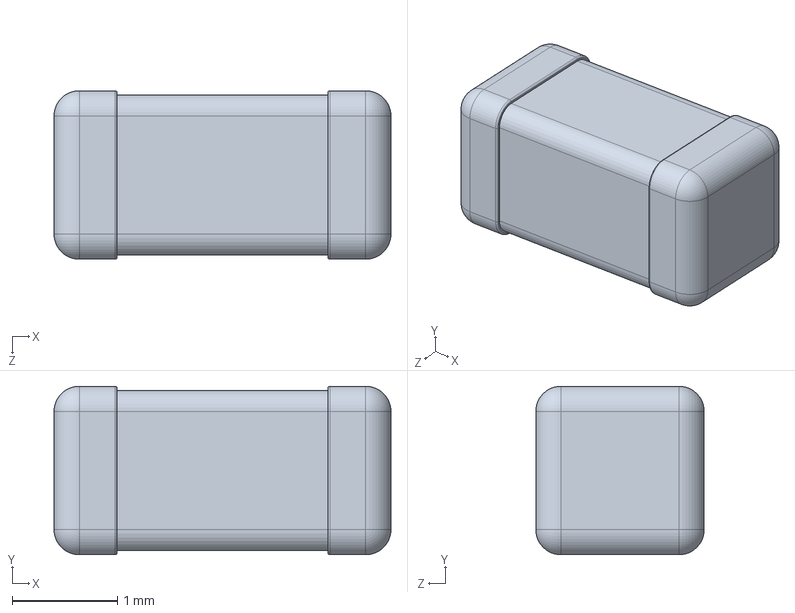
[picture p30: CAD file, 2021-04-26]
models/Arduino Due/Capacitor.SLDPRT
3.20 x 1.60 x 1.60 mm

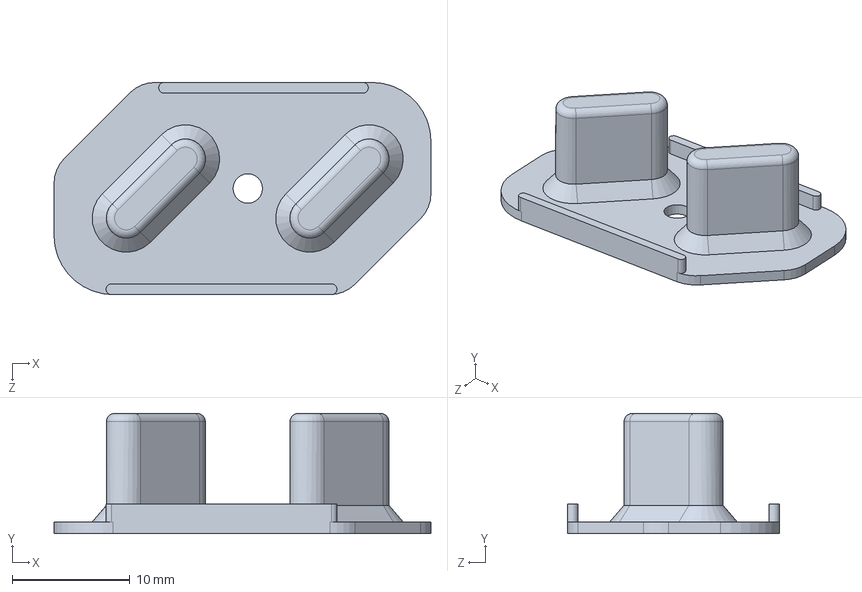
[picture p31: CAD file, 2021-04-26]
models/MembraneStart.SLDPRT
32.0 x 10.2 x 18.0 mm

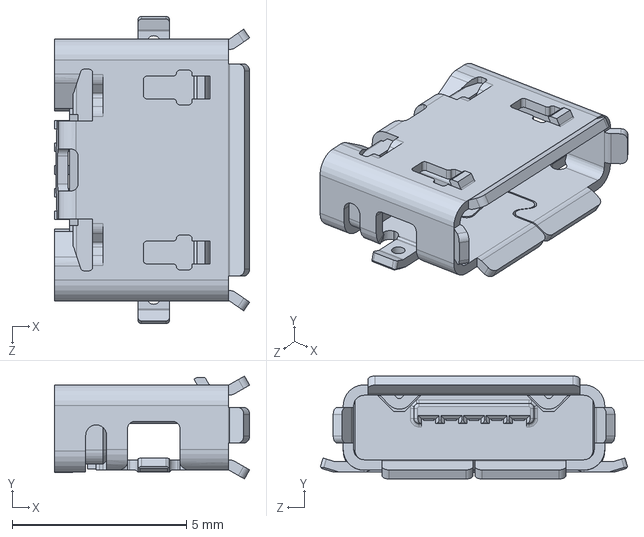
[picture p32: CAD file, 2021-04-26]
models/Arduino Due/MicroUSB AB - Hirose - ZX62-AB-5PA.SLDPRT
5.60 x 2.95 x 8.80 mm

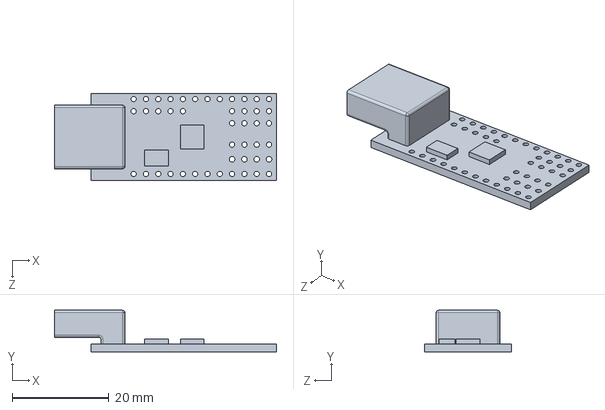
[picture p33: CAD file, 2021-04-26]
models/USBHost.SLDPRT
46.0 x 8.60 x 18.0 mm

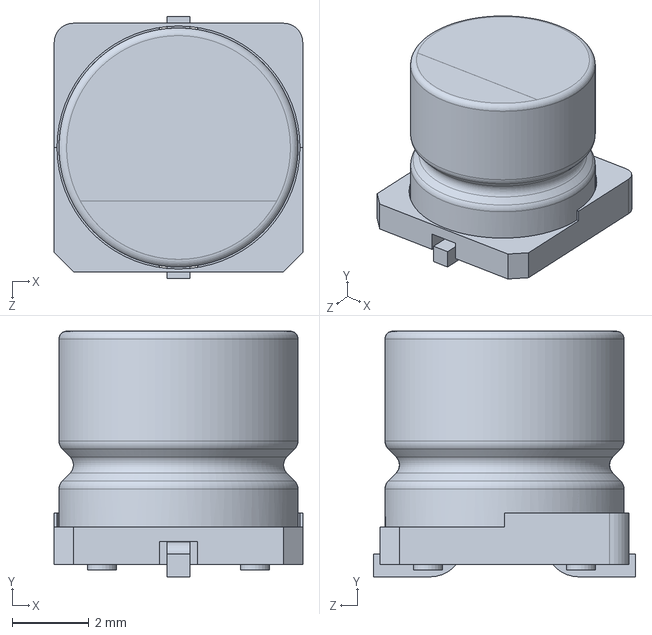
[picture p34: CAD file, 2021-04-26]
models/Arduino Due/Capacitor - Nichicon - UUR1C101MCL1GS.SLDPRT
6.50 x 6.42 x 6.85 mm

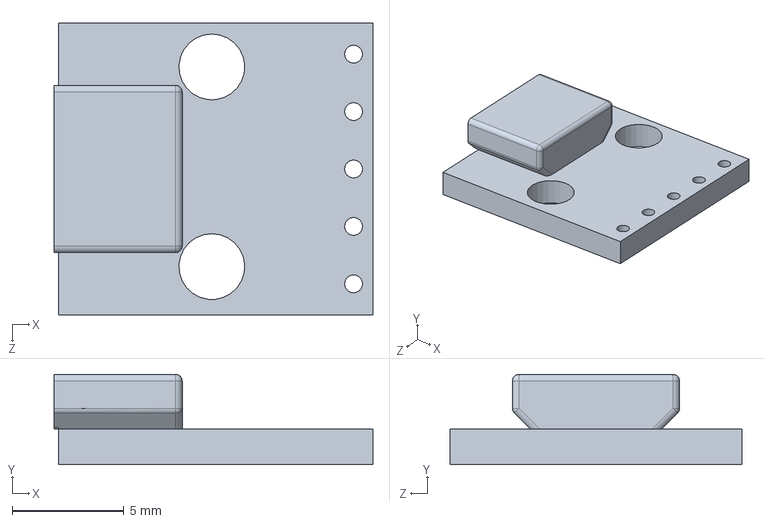
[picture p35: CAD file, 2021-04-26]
models/USBBreakout.SLDPRT
14.3 x 4.05 x 13.1 mm

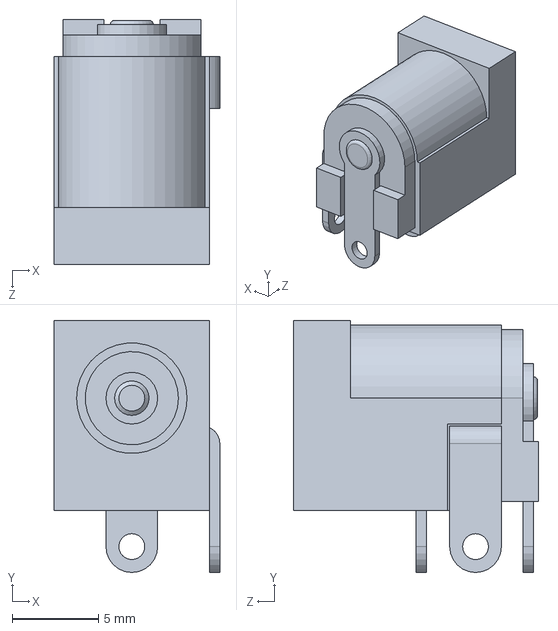
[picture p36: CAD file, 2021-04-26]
models/Arduino Due/Power Jack - Kycon - KLDHCX-0202-A.SLDPRT
9.60 x 14.6 x 14.2 mm

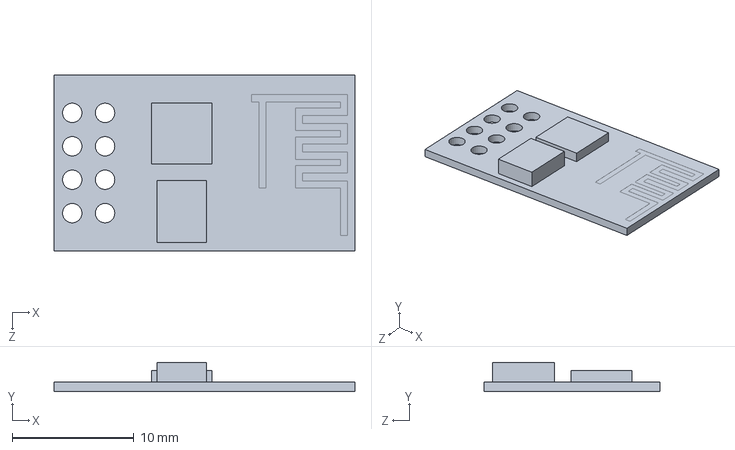
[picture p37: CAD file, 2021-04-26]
models/ESP8266.SLDPRT
24.8 x 2.40 x 14.4 mm

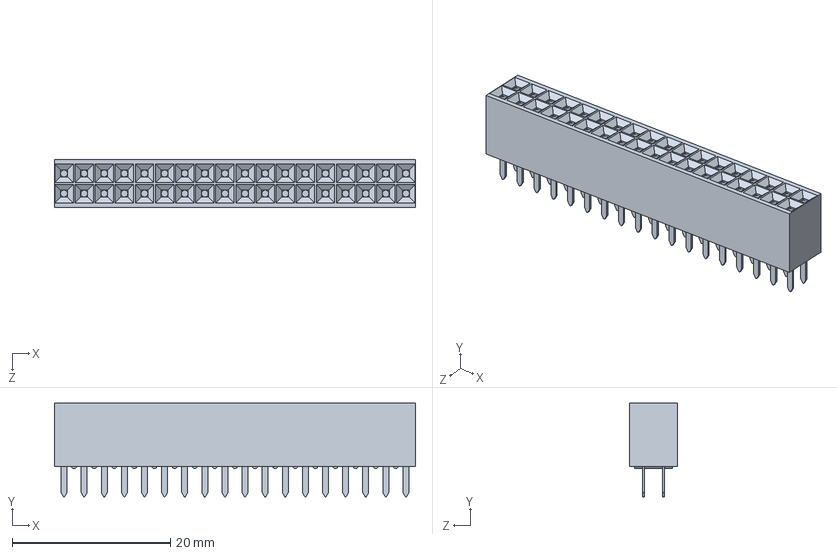
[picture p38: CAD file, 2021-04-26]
models/Arduino Due/Berg Header Receptacle 2.54 x 36 - FCI - 66953-018LF.SLDPRT
45.6 x 11.8 x 6.10 mm

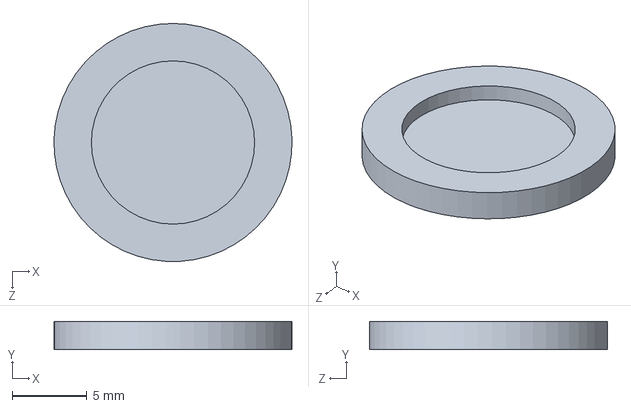
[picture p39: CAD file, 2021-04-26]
models/Volume.SLDPRT
15.9 x 1.90 x 15.9 mm

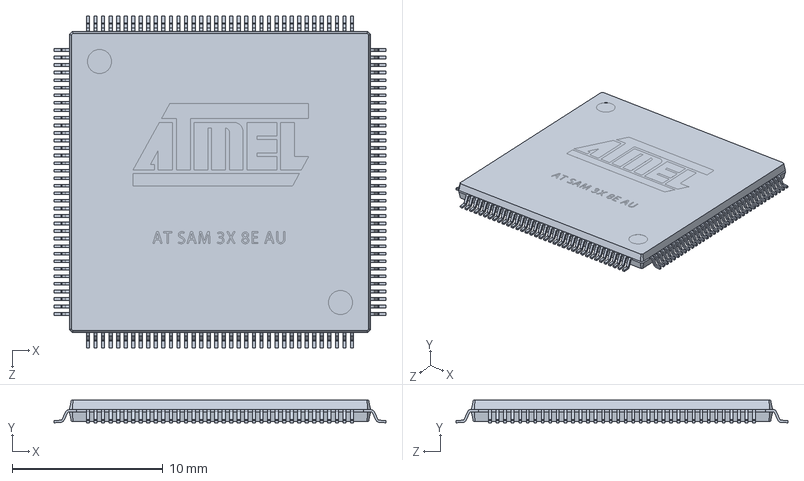
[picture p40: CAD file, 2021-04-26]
models/Arduino Due/Microchip - Atmel - SAM3X8EAU.SLDPRT
22.0 x 1.50 x 22.0 mm

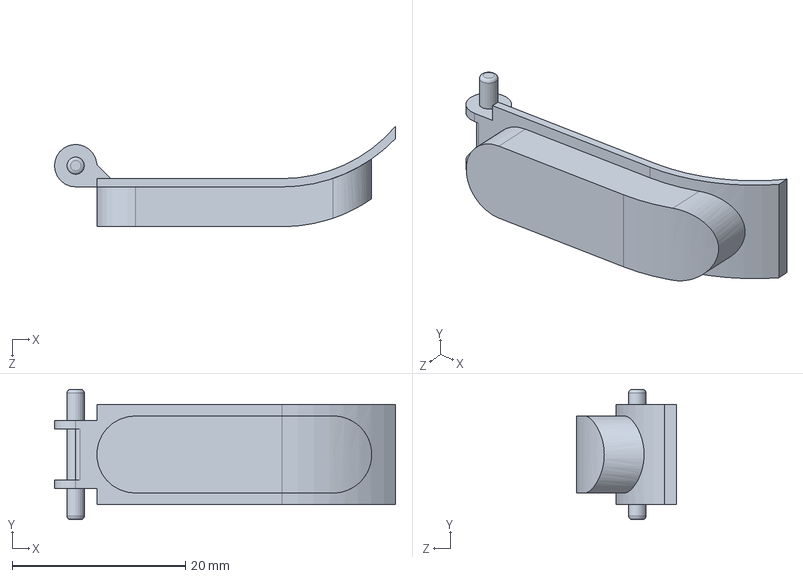
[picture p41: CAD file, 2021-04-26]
models/Gachette.SLDPRT
39.4 x 15.0 x 11.6 mm

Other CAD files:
models/Arduino Due/MicroUSB B - Hirose - ZX62D-B-5P8.SLDPRT
models/Entretoise10mm.SLDPRT
models/Arduino Due/LED - Kingbright - KPT-3216EC.SLDPRT
models/PlaqueDPad.SLDPRT
models/Arduino Due/Berg Header - 1.27 x 10.SLDPRT
models/Arduino Due/Berg Header - 2.54 x 2.SLDPRT
models/Arduino Due/Berg Header Receptacle 2.54 x 10 - FCI - 66951-010LF.SLDPRT
models/Arduino Due/Berg Header Receptacle 2.54 x 8 - FCI - 66951-008LF.SLDPRT
models/Arduino Due/MicroUSB AB - Hirose - ZX62D-AB-5P8.SLDPRT
models/Arduino Due/PCB - Arduino.SLDPRT
models/Arduino Due/Switch - ESwitch - TLE3303.SLDPRT
models/BoitierBas.SLDPRT
models/BoitierBas.STL
models/BoitierHaut.SLDPRT
models/BoitierHaut.STL
models/BoitierHautV2.STL
models/Boulon.SLDPRT
models/Bouton.SLDPRT
models/DPad.SLDPRT
models/Ecran.SLDPRT
models/Entretoise12mm.SLDPRT
models/Entretoise15mm.SLDPRT
models/Entretoise20mm.SLDPRT
models/Entretoise25mm.SLDPRT
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

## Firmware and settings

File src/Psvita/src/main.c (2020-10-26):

#ifdef __vita__
#include <psp2/sysmodule.h>
#include <psp2/kernel/threadmgr.h>
#include <psp2/kernel/processmgr.h>
#include <psp2/display.h>
#include <psp2/ctrl.h>
#include <psp2/net/net.h>
#define printf psvDebugScreenPrintf
#else
#define NO_psvDebugScreenInit
#endif

#include <psp2/kernel/processmgr.h>
//#include <SDL2/SDL.h>
//#include <SDL2/SDL_ttf.h>
//#include "debugScreen.h"

#include <unistd.h>
#include <fcntl.h>
#include <stdio.h>
#include <stdint.h>
#include <stdlib.h>
#include <string.h>
#include <inttypes.h>
#include <sys/socket.h>
#include <netinet/in.h>
#include <netdb.h>


#include "gfx.h"
#include "font.h"

//const char* font_path = "app0:/data/font.TTF";
char* serv = "192.168.43.88";
int port = 1234;

char *soko = "READ sokoban 1 10 25";
char *date = "READ date 1 1 25";

int main (__attribute__((unused)) int argc,  __attribute__((unused)) char *argv[]){
	//ajout perso
	char *msg = "NIQUE TOI";


	opendisplay(960,544);		//Setup everything for the display (640 400 Basic resolution)
	atexit(closedisplay);		//At exit use closedisplay
	initfont();

	solidrect(0,0,vxsize,vysize,0,0,0);
	copytoback(0);

	copyfromback(0);
	drawprintfxy(64,64,msg);
	copyup();


	delay(1000);

	copyfromback(0);
	drawprinttext(64,64,"HELLO WORLD\n LES GENS");
	copyup();


	delay(1000);
	// Request Part


	//char *url = NULL;// will point to wttr or rate

	//psvDebugScreenInit();
	//psvDebugScreenFont.size_w += 3;//narrow character printing
	//psvDebugScreenFont.size_h += 3;//narrow character printing
	//psvDebugScreenFont.size += 3;//narrow character printing

	//printf("Press [L]=%s%s [R]=%s%s\n", wttr[0], wttr[1], rate[0], rate[1]);

	static char net_mem[1*1024*1024];
	sceSysmoduleLoadModule(SCE_SYSMODULE_NET);
	sceNetInit(&(SceNetInitParam){net_mem, sizeof(net_mem)});

	while (42)
	{
		char *url = NULL;
		char off = 'a';


		copyfromback(0);
		drawprinttext(64,64,"L sokoban\nR date");
		drawcharxy(128,128, off);
		copyup();

		for(SceCtrlData ctrl={}; !url; sceCtrlReadBufferPositive(0,&ctrl,1)){
			if(ctrl.buttons == SCE_CTRL_LTRIGGER)
			{
				msg = soko;
				url = serv;
			}
			if(ctrl.buttons == SCE_CTRL_RTRIGGER)
			{
				msg = date;
				url = serv;
			}

			if(ctrl.buttons == SCE_CTRL_DOWN)
			{
				off--;
			}
			if(ctrl.buttons == SCE_CTRL_UP)
			{
				off++;
			}

			copyfromback(0);
			drawprinttext(64,64,"L sokoban\nR date");
			drawcharxy(128,128, off);
			copyup();
		}

		//printf("fetching %s%s...\n", url[0], url[1]);
		int fd = socket(PF_INET, SOCK_STREAM, 0);
		connect(fd, (const struct sockaddr *)&((struct sockaddr_in){.sin_family = AF_INET, .sin_port = htons(port), .sin_addr.s_addr = *(long*)(gethostbyname(url)->h_addr)}), sizeof(struct sockaddr_in));

		//char*header[] = {"GET ",url[1]," HTTP/1.1\r\n", "User-Agent: curl/PSVita\r\n", "Host: ",url[0],"\r\n", "\r\n", 0};
		//for(int i = 0; header[i]; i++)//send all request header to the server
		//	write(fd, header[i], strlen(header[i]));
		write(fd, msg, strlen(msg));

		unsigned pos = 0;
		unsigned char c, line[4096];
		char *s = (char*)malloc(4000*sizeof(char));
		char *t = s;

		while(read(fd,&c,sizeof(c)) > 0 && pos < sizeof(line))
		{
			//if (c>>6==3) // if fetched char is a UTF8
				//c = readUTF(c,fd); // convert it back to ASCII
				if (c == '\n') { // end of line reached
					//psvDebugScreenPrintf("%.*s\n", pos, line); // printf the received line into the screen
					pos = 0; // reset the buffer pointer back to 0
				} else {
					line[pos] = c;
					pos++;
				}
				*t = c;
				t++;
		}
		close(fd);

		//sceSysmoduleUnloadModule(SCE_SYSMODULE_NET);
		//sceKernelDelayThread(~0);

		copyfromback(0);
		drawprinttext(64,64,s);
		copyup();

		delay(1000);
	}


	//delay(10000);
	sceNetTerm();
    sceKernelExitProcess(0);
	return 0;
}

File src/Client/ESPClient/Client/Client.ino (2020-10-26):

/*
    This sketch establishes a TCP connection to a "quote of the day" service.
    It sends a "hello" message, and then prints received data.
*/

#include <ESP8266WiFi.h>
#include <TM1637Display.h>

#ifndef STASSID
#define STASSID "Bayrou"
#define STAPSK  "deathnote"
#endif

#define CLK 27
#define DIO 14
#define RAND_PIN 13
#define LED 12

TM1637Display display(CLK, DIO);

const char* ssid     = STASSID;
const char* password = STAPSK;

const char* host = "192.168.43.88";
const uint16_t port = 1234;

void setup() {
  display.setBrightness(0x0f);
  randomSeed(analogRead(RAND_PIN));
  pinMode(LED, OUTPUT);

  Serial.begin(115200);
  Serial.println("TESTETST");

  // We start by connecting to a WiFi network

  Serial.println();
  Serial.println();
  Serial.print("Connecting to ");
  Serial.println(ssid);

  /* Explicitly set the ESP8266 to be a WiFi-client, otherwise, it by default,
     would try to act as both a client and an access-point and could cause
     network-issues with your other WiFi-devices on your WiFi-network. */
  WiFi.mode(WIFI_STA);
  WiFi.begin(ssid, password);

  while (WiFi.status() != WL_CONNECTED) {
    delay(500);
    Serial.print(".");
  }

  Serial.println("");
  Serial.println("WiFi connected");
  Serial.println("IP address: ");
  Serial.println(WiFi.localIP());
}

void loop() {
  
  char rand_key = random(0,256);
  display.showNumberDec(rand_key, false); // Expect: ___0
  
  Serial.print("connecting to ");
  Serial.print(host);
  Serial.print(':');
  Serial.println(port);

  // Use WiFiClient class to create TCP connections
  WiFiClient client;
  if (!client.connect(host, port)) {
    Serial.println("connection failed");
    delay(5000);
    return;
  }

  // This will send a string to the server
  Serial.println("sending data to server");
  
  String s = "TEST sokoban 1 10 " + String((int)rand_key);
  if (client.connected()) {
    client.println(s);
  }

  // wait for data to be available
  unsigned long timeout = millis();
  while (client.available() == 0) {
    if (millis() - timeout > 5000) {
      Serial.println(">>> Client Timeout !");
      client.stop();
      delay(60000);
      return;
    }
  }

  // Read all the lines of the reply from server and print them to Serial
  Serial.println("receiving from remote server");
  char c;
  // not testing 'client.connected()' since we do not need to send data here
  while (client.available()) {
    c = static_cast<char>(client.read());
    Serial.print(c);
  }
  Serial.println("\n");
  Serial.println((int)rand_key);
  Serial.println((int)c);
  if (c != rand_key)
  {
    Serial.println("Error on receiving data");  
    digitalWrite(LED, HIGH);
  }
  else
    digitalWrite(LED, LOW);
   
  // Close the connection
  Serial.println();
  Serial.println("closing connection");
  client.stop();

  delay(3000); // execute once every 5 minutes, don't flood remote service
}
